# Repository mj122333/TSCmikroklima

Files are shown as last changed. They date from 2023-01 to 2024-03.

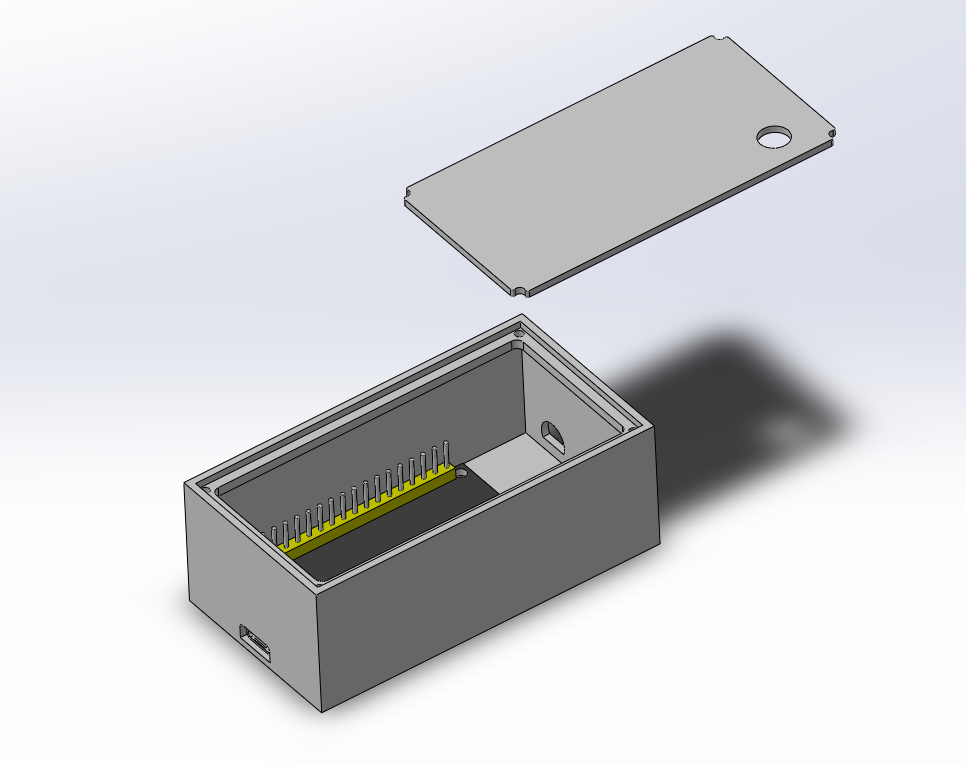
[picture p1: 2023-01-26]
node/3D_printing/slike/asembli_solid_noBatt_img2.PNG

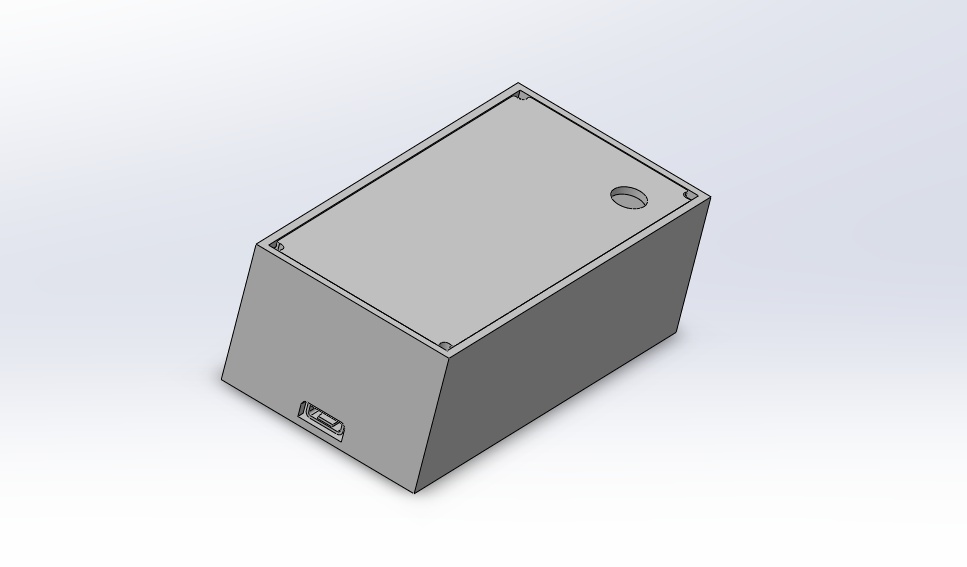
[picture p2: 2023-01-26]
node/3D_printing/slike/asembli_solid_noBatt_img1.PNG

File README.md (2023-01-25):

<div align="center">

[][contributors-url]
[][stars-url]

</div>

# TSC Mikroklima

TSC Mikroklima je projekt koji se bavi izgradnjom IoT sistema za mjerenje raznih parametara u školi.  
Sistem koristi senzore koji mjere: 
* temperaturu
* vlagu
* pritisak zraka
* otvorene prozore

Podaci se prikupljaju i prenose na cloud platformu gdje se obrađuju i prikazuju na različite načine, kao što su grafovi, tabele i mape. Cilj projekta
je pružiti školi uvid u stanje učionica i pomoći u održavanju optimalnih uvjeta za učenje. Također, sistem će biti dostupan putem web sučelja za lakše praćenje i 
upravljanje.Sada radimo na izgradnji i testiranju sistema i planiramo ga uključiti u školske aktivnosti u najkraćem mogućem roku.

Ovaj projekt sadrži sljedeće jezike/frameworke/biblioteke:
* [][Cpp-url]
* [][JSON-url]
* [][PHP-url]
* [][MySQL-url]
* [][JS-url]

<!-- GETTING STARTED -->
## Korištenje
pojašnjanje kako koristiti djelove ovog projekta.

### JSON upit za [submit.php](https://github.com/mj122333/TSCmikroklima/blob/main/server/submit.php)
Objašnjenje:

```JSON
{
  "MAC": "#MAC adresa uređaja koji šalje POST zahtjev",
  "temp": {
    "#adresa senzora za temperaturu": "#temperatura u decimalnom zapisu",
    "adresa sljedećeg senzora za temperaturu": "#temperatura u decimalnom zapisu",
    "adresa n-tog senzora za temperaturu": "#temperatura u decimalnom zapisu"
  },
  "statusObjekt": {
    "#pin senzora za status  objekta": "#je li prozor otvoren",
    "#pin sljedećeg senzora za status objekta": "#je li prozor otvoren",
    "#pin n-tog senzora za status objekta": "#je li prozor otvoren"
  }
}
```

Primjer:
```JSON
{
  "MAC": "01-23-45-67-89-AB",
  "temp": {
    "0x123456789ABCDEF0": 23.42,
    "0x123456789ABCDEF1": 22,
    "0x123456789ABCDEF2": 21.1
  },
  "statusObjekt": {
    "1": 1,
    "4": 0,
    "23": 1
  }
}
```
[Primjer upita u Postman-u](https://github.com/mj122333/TSCmikroklima/blob/main/server/skola-IoT.postman_collection.json) (importati u Postman)

[CPP]: https://img.shields.io/badge/C++-909DAB?style=for-the-badge&logo=cplusplus&logoColor=00599C
[CPP-url]: https://isocpp.org/

[JSON]: https://img.shields.io/badge/JSON-000?style=for-the-badge&logo=JSON
[JSON-url]: https://www.json.org/

[PHP]: https://img.shields.io/badge/PHP-777BB4?style=for-the-badge&logo=php&logoColor=333
[PHP-url]: https://isocpp.org/

[MySQL]: https://img.shields.io/badge/MySQL-4479A1?style=for-the-badge&logo=mysql&logoColor=FFF
[MySQL-url]: https://www.mysql.com/

[JS]: https://img.shields.io/badge/javascript-000000?style=for-the-badge&logo=javascript&logoColor=F7DF1E
[JS-url]: https://www.javascript.com/

[contributors-shield]: https://img.shields.io/github/contributors/mj122333/TSCmikroklima.svg?style=for-the-badge
[contributors-url]: https://github.com/mj122333/TSCmikroklima/graphs/contributors

[stars-shield]: https://img.shields.io/github/stars/mj122333/TSCmikroklima.svg?style=for-the-badge
[stars-url]: https://github.com/mj122333/TSCmikroklima/stargazers

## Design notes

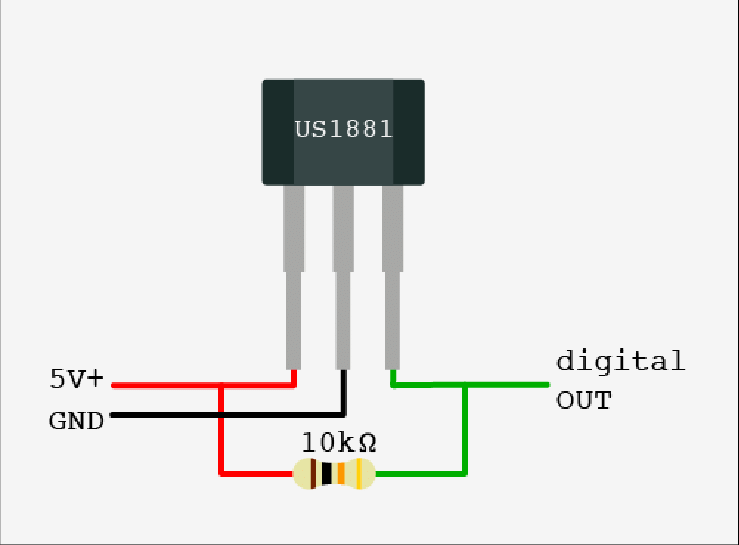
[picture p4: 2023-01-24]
node/scheme/komponente_pinout/us1881_hall.png

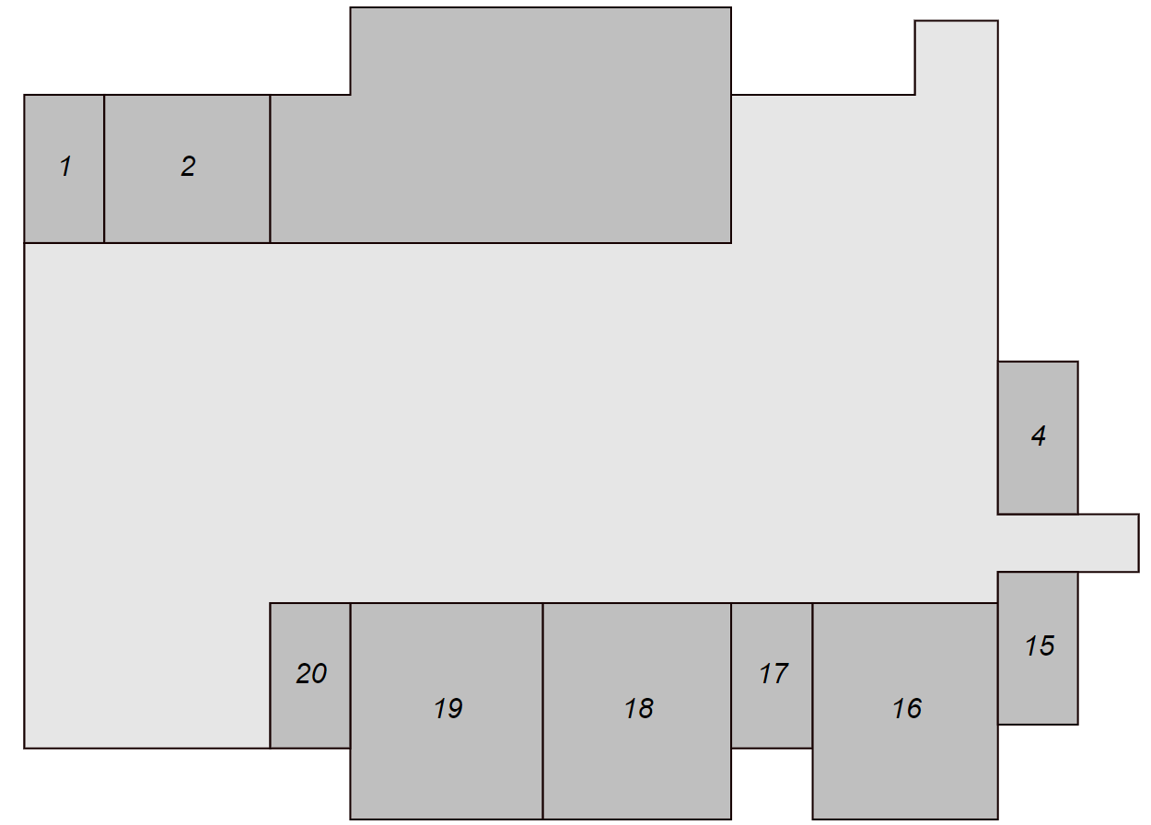
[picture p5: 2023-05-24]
server/slike/tlocrt-prizemlje-tv.png

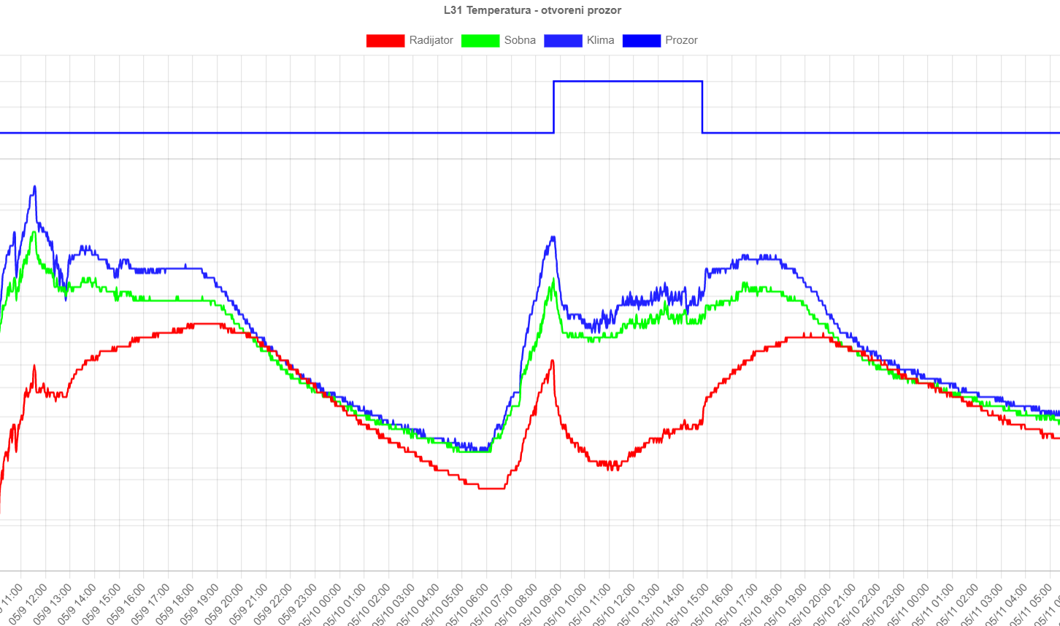
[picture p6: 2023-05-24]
server/slike/graf.png

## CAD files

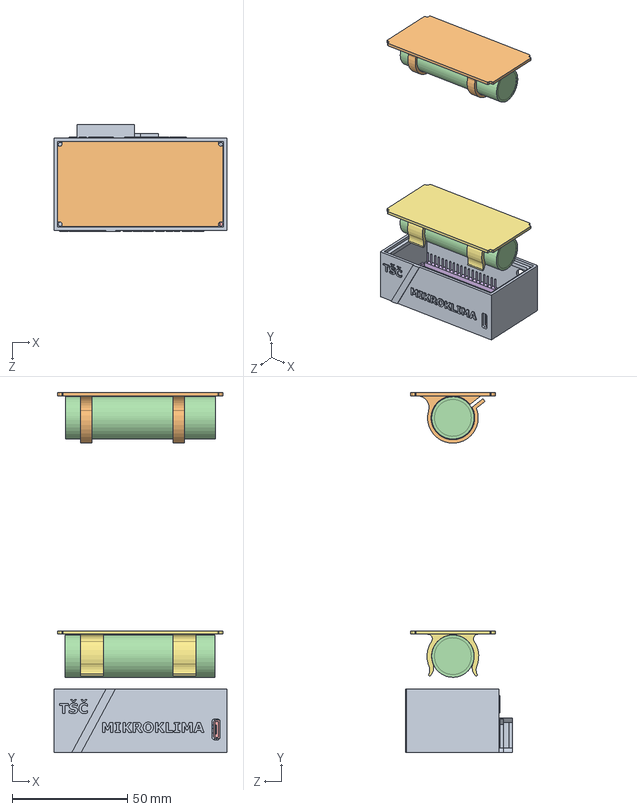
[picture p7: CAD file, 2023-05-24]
node/3D_printing/asembli_solid_Batt.SLDASM
75.0 x 156.1 x 46.5 mm
main_box_donjiDio_sBaterijom
main_box_poklopac_sBaterijom
main_ziceClamp_bezBaterije
battery_model x 2
charge_controller
ESP32_model
main_box_poklopac_sBaterijom_NoScrews

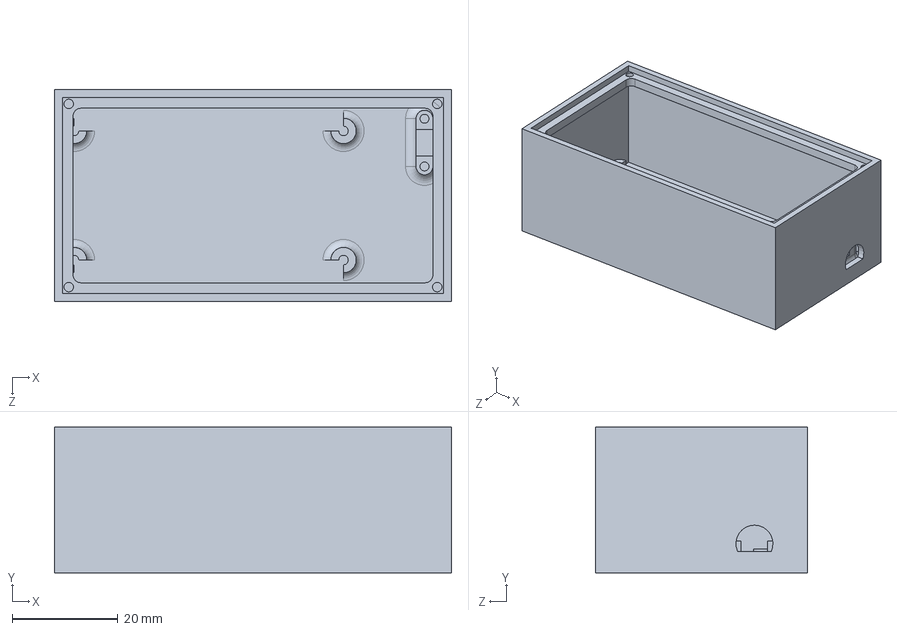
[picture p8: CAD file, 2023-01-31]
node/3D_printing/Main_box/bez_baterije/main_box_donjiDio_bezBaterije.SLDPRT
75.0 x 27.5 x 40.0 mm

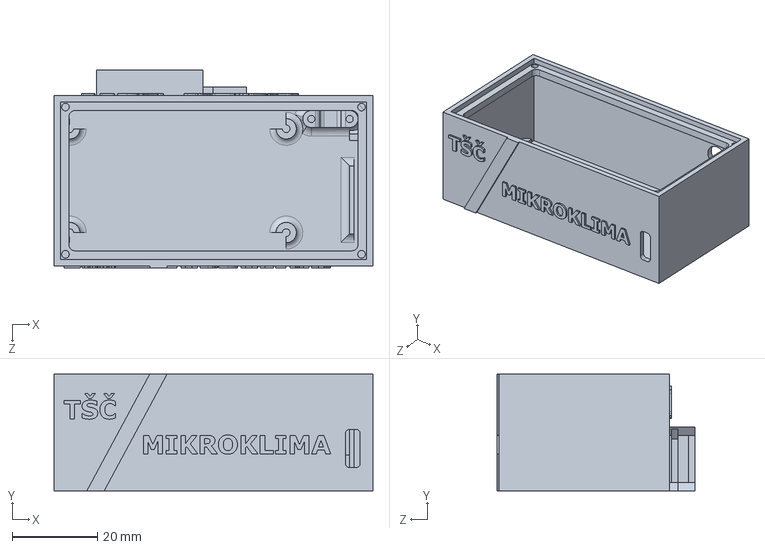
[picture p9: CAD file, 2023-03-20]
node/3D_printing/Main_box/main_box_donjiDio_sBaterijom.SLDPRT
75.0 x 27.5 x 46.5 mm

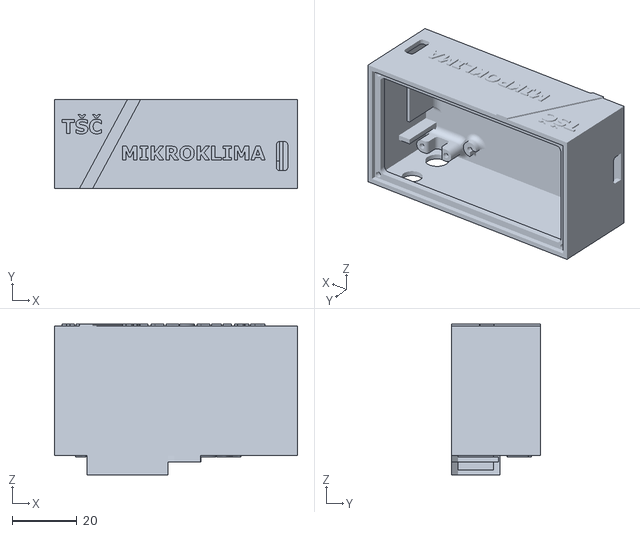
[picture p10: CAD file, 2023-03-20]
node/3D_printing/3D_printing_stl/main_box_donjiDio_sBaterijom.STL
75.0 x 27.5 x 46.5

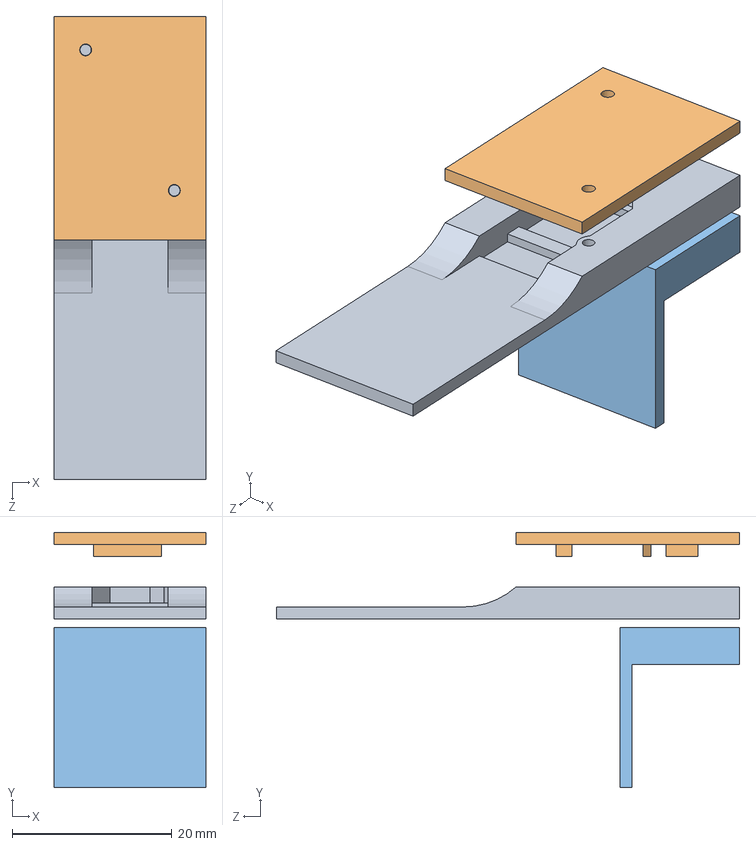
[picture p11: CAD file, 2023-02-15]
node/3D_printing/asembli_senzor_prozor.SLDASM
19.0 x 31.9 x 58.0 mm
hall_mount_zaProzor_kutijica
hall_mount_zaProzor_poklopac
magnet_mount

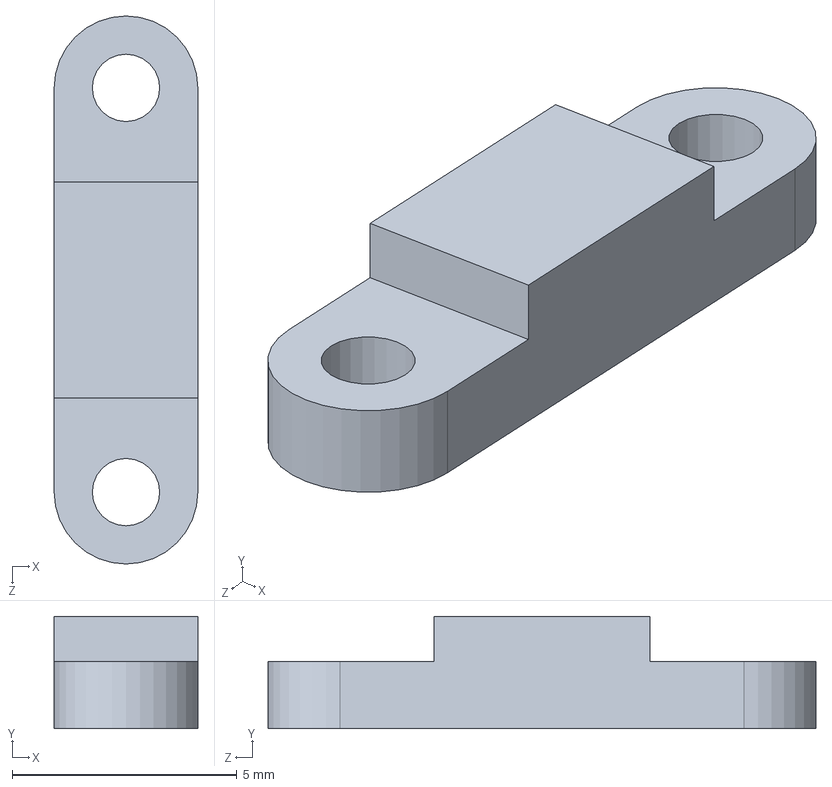
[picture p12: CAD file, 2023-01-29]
node/3D_printing/Main_box/bez_baterije/main_ziceClamp_bezBaterije.SLDPRT
3.20 x 2.50 x 12.2 mm

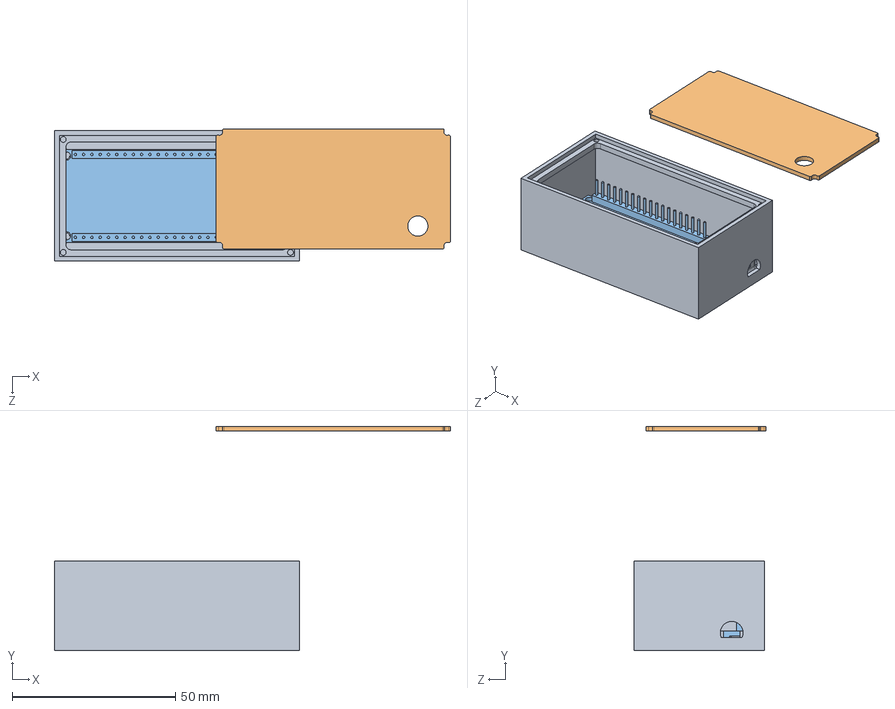
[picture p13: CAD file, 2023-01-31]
node/3D_printing/asembli_solid_noBatt.SLDASM
121.3 x 68.8 x 40.6 mm
main_box_donjiDio_bezBaterije
main_box_poklopac_bezBaterije
ESP32_model

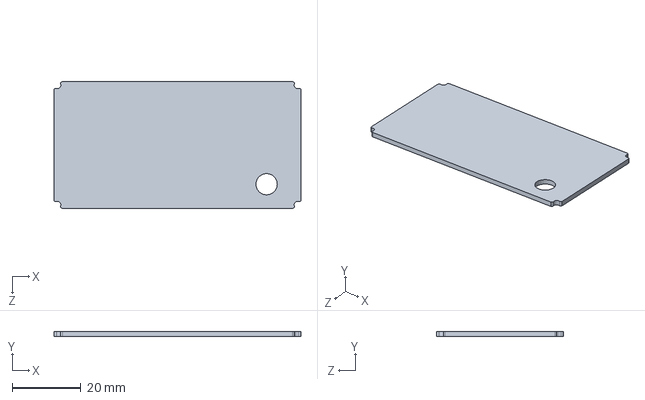
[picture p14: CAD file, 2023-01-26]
node/3D_printing/Main_box/bez_baterije/main_box_poklopac_bezBaterije.SLDPRT
71.8 x 1.50 x 36.8 mm

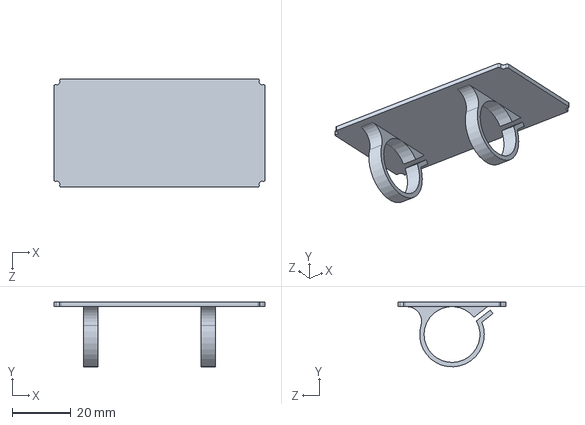
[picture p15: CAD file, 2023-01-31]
node/3D_printing/Main_box/main_box_poklopac_sBaterijom.SLDPRT
71.8 x 22.0 x 36.8 mm

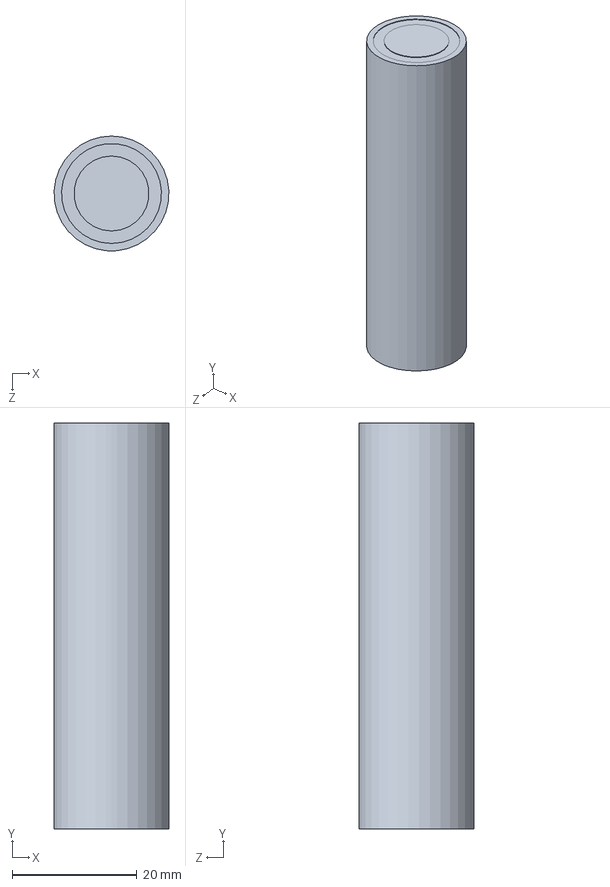
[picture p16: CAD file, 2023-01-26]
node/3D_printing/3D_component_models/battery_model.SLDPRT
18.4 x 65.0 x 18.4 mm

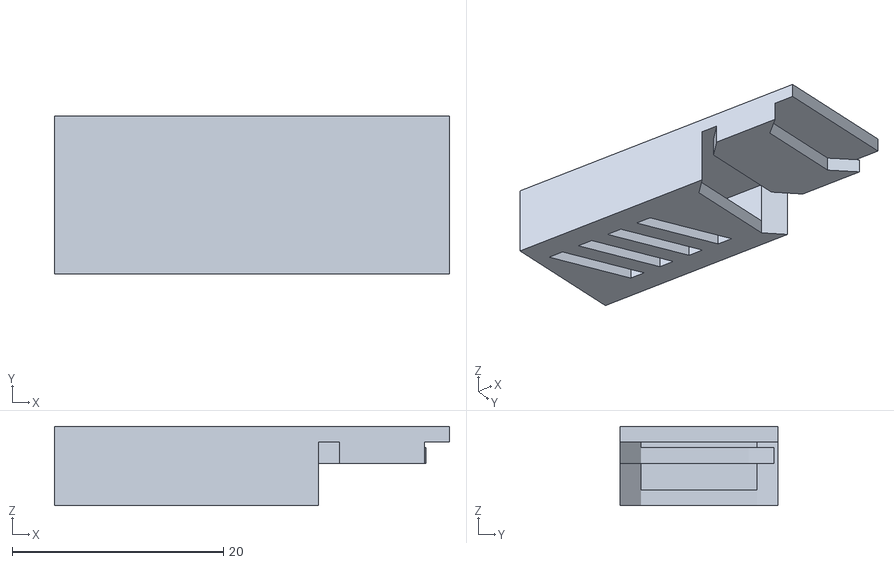
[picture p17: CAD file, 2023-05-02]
node/3D_printing/3D_printing_stl/room_temp.STL
37.4 x 15.0 x 7.50

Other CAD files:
node/3D_printing/step_files_blend/main_box_donjiDio_sBaterijom.STEP
node/3D_printing/3D_printing_stl/main_box_poklopac_sBaterijom.STL
node/3D_printing/3D_printing_stl/main_box_donjiDio_bezBaterije.STL
node/3D_printing/3D_printing_stl/main_ziceClamp_bezBaterije.STL
node/3D_printing/step_files_blend/main_ziceClamp_bezBaterije.STEP
node/3D_printing/3D_printing_stl/main_box_poklopac_bezBaterije.STL
node/3D_printing/senzori_kucista/room_temp.SLDPRT
node/3D_printing/3D_component_models/ESP32_model.SLDPRT
node/3D_printing/3D_component_models/charge_controller.SLDPRT
node/3D_printing/3D_printing_stl/18b20_mount_radijator.STL
node/3D_printing/3D_printing_stl/hall_mount_zaProzor_kutijica.STL
node/3D_printing/3D_printing_stl/hall_mount_zaProzor_poklopac.STL
node/3D_printing/3D_printing_stl/magnet_mount.STL
node/3D_printing/3D_printing_stl/main_box_poklopac_sBaterijom_NoScrews.STL
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

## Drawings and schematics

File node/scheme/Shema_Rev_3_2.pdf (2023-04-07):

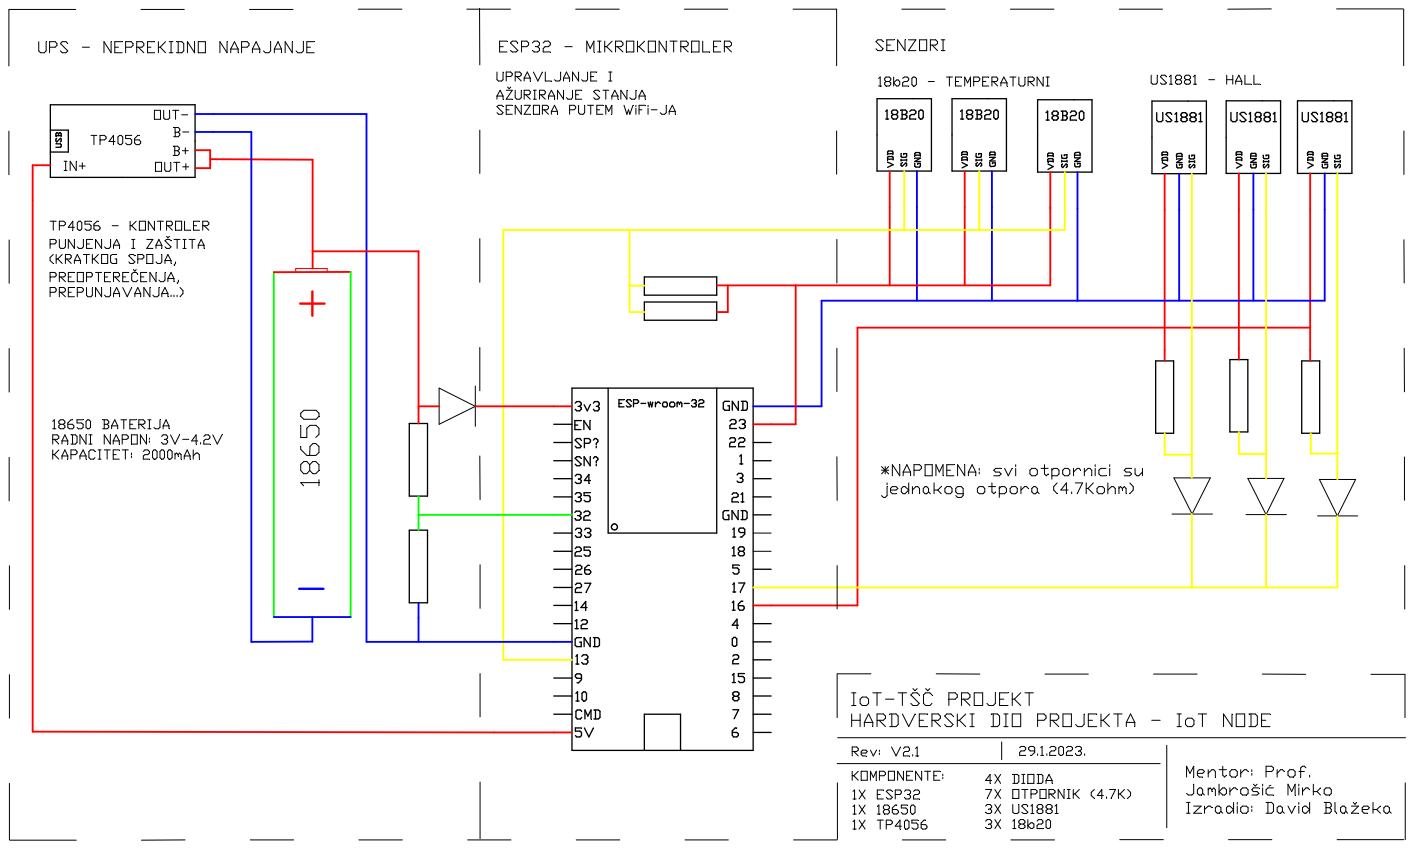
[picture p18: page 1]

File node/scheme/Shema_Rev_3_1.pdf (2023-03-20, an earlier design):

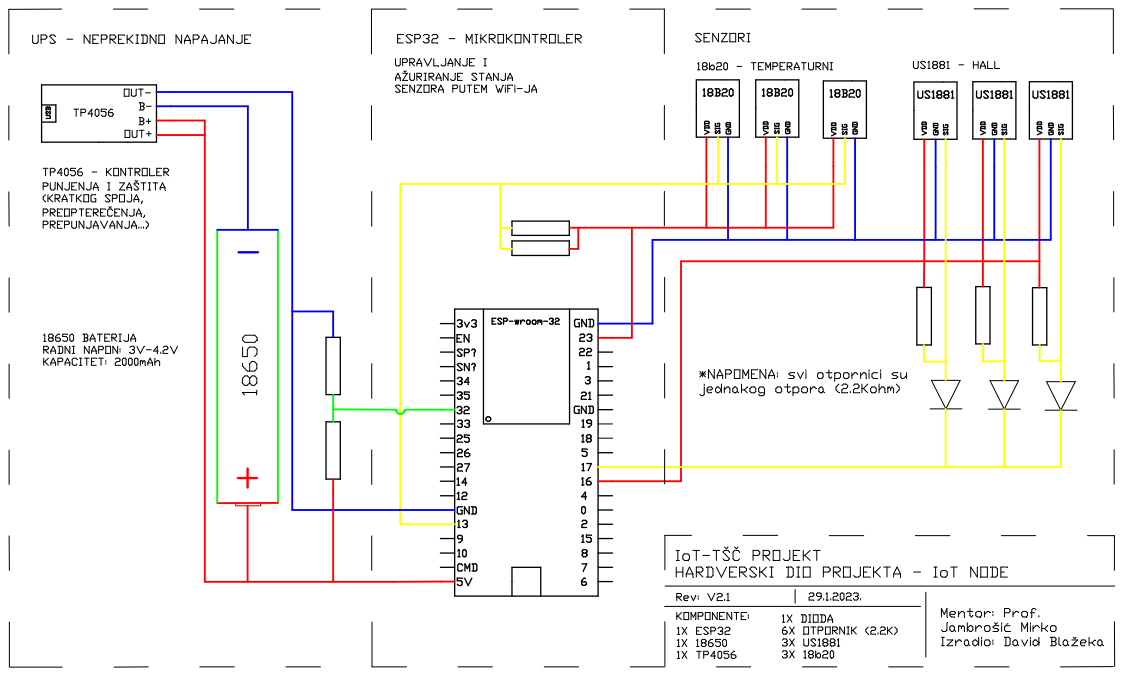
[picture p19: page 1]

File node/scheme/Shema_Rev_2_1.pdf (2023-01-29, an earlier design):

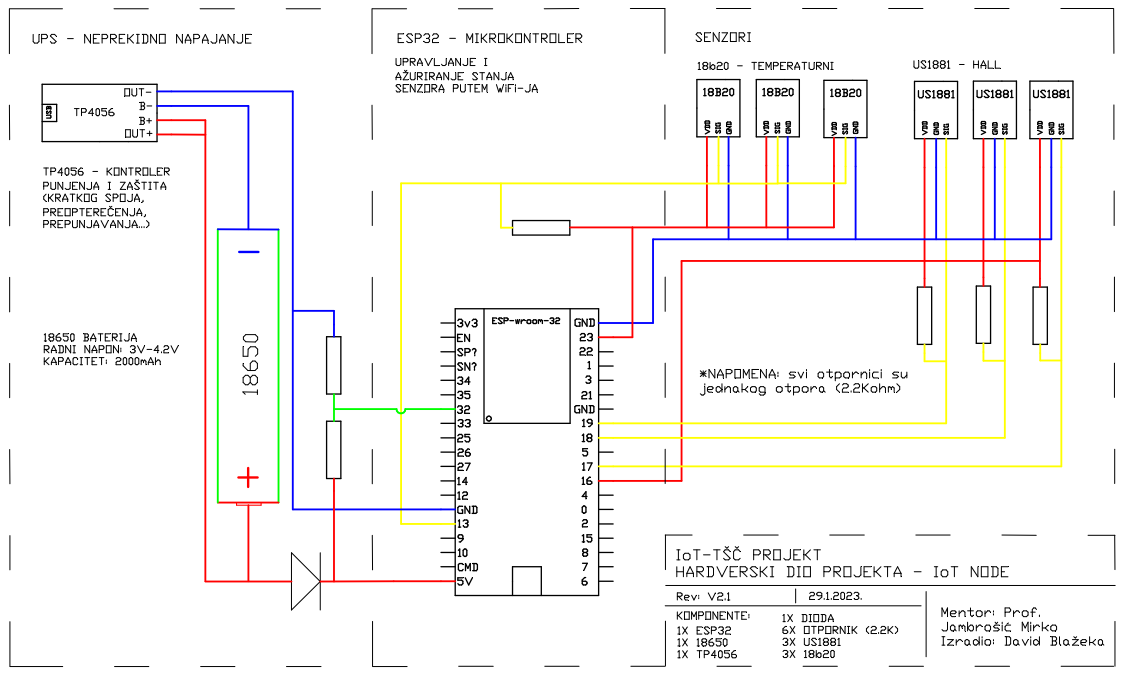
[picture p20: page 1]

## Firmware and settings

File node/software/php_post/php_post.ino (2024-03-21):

// kod za custom implementaciju...

#include <DallasTemperature.h>
#include <HTTPClient.h>
#include <OneWire.h>
#include <WiFiManager.h> // https://github.com/tzapu/WiFiManager

bool wm_nonblocking = false; // change to true to use non blocking
WiFiManager wm;
WiFiManagerParameter custom_field;

String serverName = "https://jambrosic.xyz/mikroklima/submit.php";

unsigned long lastTime = 0;
unsigned long timerDelay = 60000;
#define uS_TO_S_FACTOR 1000000
#define TIME_TO_SLEEP  60
String key = "esp32";  // super tajni key
String macAdresa = "";
String zaSlanjeT = "";
String zaSlanjeH = "";
String zaSlanjeM = "";
int broj_senzora = 0;
bool led_stanje = LOW;
bool zadnjeStanjeHall[3];
bool statusObjekt[3];
#define ONE_WIRE_BUS 13
#define B20_POWER 23
#define HALL_POWER 16
#define HALL_READ1 17
//#define HALL_READ2 18
//#define HALL_READ3 19
#define BATT 32
#define RED_LED 5
#define GREEN_LED 18
#define BLUE_LED 19

OneWire oneWire(ONE_WIRE_BUS);
DallasTemperature sensors(&oneWire);
DeviceAddress Thermometer;

void setup() {
    Serial.begin(115200);
    pinMode(21, OUTPUT);
    digitalWrite(21, HIGH); // status led
    pinMode(RED_LED, OUTPUT);
    pinMode(GREEN_LED, OUTPUT);
    pinMode(BLUE_LED, OUTPUT);
    delay(2000);
    Serial.println("Spajanje");
    Serial.print("MAC: ");
    macAdresa = WiFi.macAddress();
    Serial.println(macAdresa);
    spoji();
    spojeno();
    Serial.println("");
    Serial.print("IP: ");
    Serial.println(WiFi.localIP());
    Serial.println(WiFi.RSSI());
    pinMode(HALL_POWER, OUTPUT);
    pinMode(HALL_READ1, INPUT_PULLUP);
    //pinMode(HALL_READ2, INPUT_PULLUP);
    //pinMode(HALL_READ3, INPUT_PULLUP);
    pinMode(BATT, INPUT);
    pinMode(B20_POWER, OUTPUT);
    digitalWrite(B20_POWER, HIGH);  // no deep sleep
    esp_sleep_enable_timer_wakeup(TIME_TO_SLEEP * uS_TO_S_FACTOR);
}

void loop() {
    /*
     * slanje podataka, određeni interval vremena (timerDelay)
     * ako dođe do promjene u statusObjekt informacije se šalju odmah
     * interval slanja podataka neovisan je o promjeni statusaObjekta (šalje
     * podatke na timerDelay)
     */
    //if ((millis() - lastTime) > timerDelay) { 
        mjeri_temperaturu();  // funkcija koja ažurira temperature
        get_metadata();       // WiFi status i baterija
        hallRefresh();        // očitavanje stanja hall senzora
        pushData();  // funkcija koja šalje vrijednosti Gotalu i Biškupu
      //  lastTime = millis();
    //}
    WiFi.disconnect();
    off();
    Serial.flush(); 
    esp_deep_sleep_start();  
}

void hallRefresh() {                // void funkcija očitanja statusaObjekta
    digitalWrite(HALL_POWER, LOW);  // reset hall senzora
    delay(100);
    digitalWrite(HALL_POWER, HIGH);
    delay(100);  // pricekati da se hallovi stabiliziraju?
    zaSlanjeH = "";
    zaSlanjeH = ",\"statusObjekt\" : {";
    for (int i = 0; i < 3; i++) { //do 3 za 3 hall senzora
        statusObjekt[i] =
            digitalRead(17);  // 17, 18, 19 su ulazi senzora statusObjekt-a, obrisano + i jer se koristi samo jedan pin
        delay(20);
        if (statusObjekt[i] !=
            digitalRead(17))  // ako dva slijedna ocitanja daju razlicite
                                  // vrijednosti -> preskoci
            continue;
        /*
         //ovaj dio moramo prodiskutirati
         if(zadnjeStanjeHall[i] != statusObjekt[i]){//
           zadnjeStanjeHall[i] = statusObjekt[i]; //ako je stanje različito
         prijašnjem, zapisuje se u listu lastTime = millis() + timerDelay;
         //Slanje ažuriranih podataka, odmah (ukoliko je doslo do promjene barem
         jednog senzora)
         }
         //ovaj dio se koristio kod instantnog ažuriranja podataka (čim se
         promjenilo stanje prozora)
         */
        zaSlanjeH +=
            "\"" + String(17 + i) + "\" : \"" + statusObjekt[i] +
            "\"";  // spremanje stanja u zaSlanjeH string (u json formatu)
        if (i != 2) zaSlanjeH += ",";
    }
    zaSlanjeH += "}";
}

void pushData() {
    if (WiFi.status() == WL_CONNECTED) {
        spojeno();
        HTTPClient http;

        http.begin(serverName.c_str());
        Serial.println(serverName.c_str());
        http.addHeader("Content-Type", "application/json");

        // String jsonData =  "{\"MAC\" : \"" + macAdresa + "\",\"key\" :
        // \"esp32\",\"temp\" : {\"0xtest1\" : \"15\",\"0xtest2\" : \"20\" ,
        // \"0xtest3\" : \"25\"}}";

        String jsonData = "{\"MAC\" : \"" + macAdresa + "\",\"key\" : \"" +
                          key + "\"," + zaSlanjeT + zaSlanjeH + zaSlanjeM + "}";

        Serial.println(jsonData); // debug u konzoli
        zaSlanjeT = "";  // reset stringa za temperature
        zaSlanjeH = "";  // reset stringa za statusObjekta (hall)
        zaSlanjeM = "";  // reset stringa za metadata

        int httpResponseCode = http.POST(jsonData.c_str());

        if (httpResponseCode > 0) {
            Serial.print("HTTP Response code: ");
            Serial.println(httpResponseCode);
            String payload = http.getString();
            Serial.println(payload);
        } else {
            Serial.print("Error code: ");
            Serial.println(httpResponseCode);
        }
        http.end();
    } else {
        spoji();
    }
}

void get_metadata() {
    zaSlanjeM = ",\"metadata\" : {\"wifi_rssi\" : \"";
    zaSlanjeM += WiFi.RSSI();
    zaSlanjeM += "\",\"baterija\" : \"";
    float ulazA = analogRead(BATT);
    float napon = ulazA / 4096 * 6.6;  // 3.3V nominal, naponsko djelilo 1/2
    zaSlanjeM += uint16_t((napon + 0.3)*1000);          //+0.3 kalibracija, mV conv
    zaSlanjeM += "\"}";
}

void mjeri_temperaturu() {
    digitalWrite(B20_POWER, HIGH);
    delay(1000);
    sensors.begin();  // inicijalizacija senzora u svakom krugu očitanja (omogućuje hot-swap)
    delay(1000);
    broj_senzora = sensors.getDeviceCount();  // spremanje broja senzora
    sensors.requestTemperatures();  // očitavanje temperatura pomoću biblioteke
    delay(100);
    zaSlanjeT += "\"temp\" : {\"";  // početak json dijela s temperaturnim senzorima
    for (int sen = 0; sen < broj_senzora; sen++) {
        if (sensors.getTempCByIndex(sen) == -127) continue;
        sensors.getAddress(Thermometer, sen);
        zaSlanjeT += printAddress(Thermometer);  // očitavanje adrese
        zaSlanjeT += "\" : \"";
        zaSlanjeT += sensors.getTempCByIndex(sen);  // očitavanje temperature
        if (sen != broj_senzora - 1) zaSlanjeT += "\",\"";
        delay(500);  // reading cooldown, u fazi testiranja/traženja problema
    }
    zaSlanjeT += "\"}";
    digitalWrite(B20_POWER, LOW);
}

String printAddress(DeviceAddress deviceAddress)  // funkcija za adresu temperaturnih senzora
{
    String adresa = "0x";
    for (uint8_t i = 0; i < 8; i++) {
        adresa += String(deviceAddress[i], HEX);
    }
    return adresa;
}

void spajanje(){
  digitalWrite(GREEN_LED, LOW);
  digitalWrite(BLUE_LED, HIGH);
  digitalWrite(RED_LED, LOW);
}

void spojeno(){
  digitalWrite(RED_LED, HIGH);
  digitalWrite(GREEN_LED, LOW);
  digitalWrite(BLUE_LED, LOW);
}

void off(){
  digitalWrite(RED_LED, HIGH);
  digitalWrite(GREEN_LED, HIGH);
  digitalWrite(BLUE_LED, HIGH);
}

void spoji(){
  spajanje();
  WiFi.mode(WIFI_STA); // explicitly set mode, esp defaults to STA+AP  
  Serial.begin(115200);
  Serial.setDebugOutput(true);  
  delay(3000);
  Serial.println("\n Starting");
  
  // wm.resetSettings(); // wipe settings

  if(wm_nonblocking) wm.setConfigPortalBlocking(false);

  // add a custom input field
  int customFieldLength = 40;
  const char* custom_radio_str = "<br/><label for='customfieldid'>Custom Field Label</label><input type='radio' name='customfieldid' value='1' checked> One<br><input type='radio' name='customfieldid' value='2'> Two<br><input type='radio' name='customfieldid' value='3'> Three";
  new (&custom_field) WiFiManagerParameter(custom_radio_str); // custom html input
  
  wm.addParameter(&custom_field);
  wm.setSaveParamsCallback(saveParamCallback);

  std::vector<const char *> menu = {"wifi","info","param","sep","restart","exit"};
  wm.setMenu(menu);
  wm.setClass("invert");

  //wm.setSTAStaticIPConfig(IPAddress(10,0,1,99), IPAddress(10,0,1,1), IPAddress(255,255,255,0)); // set static ip,gw,sn
  // wm.setConnectTimeout(20); // how long to try to connect for before continuing
  wm.setConfigPortalTimeout(60); // auto close configportal after n seconds

  bool res;
  res = wm.autoConnect("TSC_mikroklima","password"); // password protected ap

  if(!res) {
    Serial.println("Failed to connect or hit timeout");
    ESP.restart();
  } 
  else {
    //if you get here you have connected to the WiFi    
    spojeno();
    Serial.println("connected...yeey :)");
  }
}

String getParam(String name){
  //read parameter from server, for customhmtl input
  String value;
  if(wm.server->hasArg(name)) {
    value = wm.server->arg(name);
  }
  return value;
}

void saveParamCallback(){
  Serial.println("[CALLBACK] saveParamCallback fired");
  Serial.println("PARAM customfieldid = " + getParam("customfieldid"));
}

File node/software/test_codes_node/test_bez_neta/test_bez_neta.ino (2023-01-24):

//kod za test jsona, OFFLINE!!
#include <OneWire.h>
#include <DallasTemperature.h>

unsigned long lastTime = 0;
unsigned long timerDelay = 10000;
String macAdresa = "";
String zaSlanjeT = "";
String zaSlanjeH = "";
int broj_senzora = 0;
bool zadnjeStanjeHall[3];
bool statusObjekt[3];
#define ONE_WIRE_BUS 13
#define HALL_POWER 16
#define HALL_READ1 17
#define HALL_READ2 18
#define HALL_READ3 19

OneWire oneWire(ONE_WIRE_BUS);
DallasTemperature sensors(&oneWire);
DeviceAddress Thermometer;
   
void setup() {
   Serial.begin(115200);
   macAdresa = "aa-B0-D0-63-C2-55";
   Serial.println(macAdresa);
   pinMode(HALL_POWER, OUTPUT);
   pinMode(HALL_READ1, INPUT);
   pinMode(HALL_READ2, INPUT);
   pinMode(HALL_READ3, INPUT);
}

void loop() {
  /*
   * slanje podataka, određeni interval vremena (timerDelay)
   * ako dođe do promjene u statusObjekt informacije se šalju odmah
   * interval slanja podataka neovisan je o promjeni statusaObjekta (šalje podatke na timerDelay)
   */
  if ((millis() - lastTime) > timerDelay) {
    mjeri_temperaturu(); //funkcija koja ažurira temperature
    pushData(); //funkcija koja šalje vrijednosti Gotalu i Biškupu
    lastTime = millis();
  }

  hallRefresh(); //"interrupt" funkcija statusObjekt-a (šalje podatke kod promjene, ne čeka timerDelay)
}

void hallRefresh(){ //void funkcija očitanja statusaObjekta
  digitalWrite(HALL_POWER, LOW); //reset hall senzora
  delay(10);
  digitalWrite(HALL_POWER, HIGH);

  zaSlanjeH = "";
  zaSlanjeH = ",\"statusObjekt\" : {";
  for(int i = 0; i < 3; i++){
    statusObjekt[i] = digitalRead(17+i); //17, 18, 19 su ulazi senzora statusObjekt-a
    if(zadnjeStanjeHall[i] != statusObjekt[i]){
      zadnjeStanjeHall[i] = statusObjekt[i]; //ako je stanje različito prijašnjem, zapisuje se u listu
      lastTime = millis() + timerDelay; //Slanje ažuriranih podataka, odmah
    }
    zaSlanjeH += "\"" + String(17+i) + "\" : \"" + statusObjekt[i] + "\""; //spremanje stanja u zaSlanjeH string (u json formatu)
    if(i != 2) zaSlanjeH += ",";
  }
  zaSlanjeH += "}";
}

void pushData(){
       //String jsonData =  "{\"MAC\" : \"" + macAdresa + "\",\"temp\" : {\"" + a1 + "\" : \"" + t1 + "\",\"" + a2 + "\" : \"" + t2 + "\" , \"" + a3 + "\" : \"" + t3 + "\"}, \"prozor\" : \"" + sp + "\"}";
       String jsonData =  "{\"MAC\" : \"" + macAdresa + "\"," + zaSlanjeT + zaSlanjeH + "}";
       Serial.println(jsonData);
       zaSlanjeT = ""; //reset stringa za temperature
       zaSlanjeH = ""; //reset stringa za statusObjekta (hall)
}

void mjeri_temperaturu(){
  sensors.begin(); //inicijalizacija senzora u svakom krugu očitanja (omogućuje hot-swap)
  broj_senzora = sensors.getDeviceCount(); //spremanje broja senzora
  sensors.requestTemperatures(); //očitavanje temperatura pomoću biblioteke
  
  zaSlanjeT += "\"temp\" : {\""; //početak json dijela s temperaturnim senzorima
  for(int sen = 0; sen < broj_senzora; sen++){
    sensors.getAddress(Thermometer, sen);
    zaSlanjeT += printAddress(Thermometer); //očitavanje adrese
    zaSlanjeT += "\" : \"";
    zaSlanjeT += sensors.getTempCByIndex(sen); //očitavanje temperature
    if(sen != broj_senzora-1) zaSlanjeT += "\",\"";
  }
  zaSlanjeT += "\"}";
}

String printAddress(DeviceAddress deviceAddress) //funkcija za adresu temperaturnih senzora
{ 
    String adresa = "";
  for (uint8_t i = 0; i < 8; i++)
  {
    adresa += "0x";
    if (deviceAddress[i] < 0x10) adresa += "0";
    adresa += String(deviceAddress[i], HEX);
    if (i < 7) adresa += ", ";
  }
  return adresa;
}

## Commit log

2023-01-11 Primanje i slanje requesta
    + php kod koji prima json tekst i koristi ga
    + slanje post metode sa esp32
2023-01-15 dohvat id senzora
    dohvat ID senzora na temelju adrese (i2c) senzora
2023-01-17 final kod v1
    - slanje MAC adrese
    - slanje adrese senzora za temperaturu 3x
    - slanje stanja prozora (bool)
    - slanje na određeni interval i odmah kad se prozor otvori (hall POWER off/on, reset)
    - auto restart ESP32 ako nije spojen na WiFi kod POST dijela
    [php_post.ino]
2023-01-17 Update php_post.ino
    Promjena temperatura iz stringa u float
2023-01-19 - esp32, dht11 za tv
2023-01-19 esp32 kod za dht11 (TV)
2023-01-24 Spremanje temperature
    Popravljeno spremanje temperature
    Popravljen zatipak u bazi podataka sa "VRIEJDNOST" u "VRIJEDNOST"
    Dodano malo pojašnjenje submit.php datoteke
2023-01-24 novi ažurirani kod
    - hot-swapable senzori
    - optimiziran način slanja (zaSlanjeT, zaSlanjeH)
    - dodani komentari
    [php_post.ino]
2023-01-24 popravljen reset halla (nova verzija)
    [php_post.ino]
2023-01-25 update kod - ignor bad sensor
2023-01-26 3d_modeli_komponente
    -esp32
    -baterija
    -punjač
    [ESP32_model.SLDPRT, battery_model.SLDPRT, charge_controller.SLDPRT]
2023-01-26 dodani dxf (pinout)
    [esp32_schem.dxf]
2023-01-26 Big 3D update
    -novi modeli
    -nova kutija (bez baterije)
    -novi poklopac
    -nove slike (assembly)
    -generirani stl za 3D printanje
    [asembli_solid_noBatt.SLDASM, main_box_donjiDio_bezBaterije.SLDPRT, main_box_donjiDio_bezBaterije.STL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]
2023-01-28 shema update
    [esp32_schem.dwg]
2023-01-29 shceme rev2_1
    [esp32_schem.dwg]
2023-01-29 shema 18b20 power pin changed
    [esp32_schem.dwg]
2023-01-29 3d printed box - ziceClamp
    [main_box_donjiDio_bezBaterije.SLDPRT, main_box_donjiDio_bezBaterije.STL, main_ziceClamp_bezBaterije.SLDPRT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]
2023-01-30 Dodan prikaz podataka direktno na tlocrtu
    ispis sobne temperature te temperature na klimi i radijatoru
2023-01-31 node i 3d printing update
    [18b20_mount_radijator.SLDPRT, 18b20_mount_radijator.STL, asembli_solid_noBatt.SLDASM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]
2023-01-31 Dodani indikatori za otvoreni i zatvoreni prozor te upozorenja
    Crveno upozorenje se ispisuje kada je temperatura nekog senzora > 35°C i otvoren prozor, a žuto ako se to dogodilo u poslijednih 8h
2023-01-31 3d printing stuff
    [asembli_solid_Batt.SLDASM, main_box_donjiDio_sBaterijom.SLDPRT, main_box_donjiDio_sBaterijom.STL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]
2023-02-02 podebljani dio za drzac baterije
    [asembli_solid_Batt.SLDASM, main_box_poklopac_sBaterijom_NoScrews.SLDPRT, main_box_poklopac_sBaterijom_NoScrews.STL]
2023-02-05 cekanje da se hallovi "stabiliziraju"
    - dodano 100ms nakon ukljucivanje hall senzora da se eventualno stabiliziraju
    - provjera debounce-a ?
2023-02-06 vracanje - provjera halla
    vracanje na slanje samo u slucaju da je doslo do promjene stanja senzora hall-a
2023-02-07 UPDATE //fixno svaku min
    [php_post.ino]
2023-02-11 3d print update
    [hall_mount_zaProzor_kutijica.SLDPRT, hall_mount_zaProzor_kutijica.STL, hall_mount_zaProzor_poklopac.SLDPRT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]
2023-02-11 3d pritn update
    [hall_mount_zaProzor_kutijica.SLDPRT, main_box_poklopac_sBaterijom_NoScrews.SLDPRT, main_box_poklopac_sBaterijom_NoScrews.STL]
2023-02-12 3d print fix
    [asembli_senzor_prozor.SLDASM, hall_mount_zaProzor_kutijica.SLDPRT, hall_mount_zaProzor_kutijica.STL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]
2023-02-13 3d update
    [hall_mount_zaProzor_kutijica.SLDPRT, hall_mount_zaProzor_kutijica.STL]
2023-02-15 3D design //.step
    [18b20_mount_radijator.STEP, ESP32_model.STEP, asembli_senzor_prozor.SLDASM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]
2023-03-20 3d i shema
    [18b20_mount_radijator.SLDPRT, asembli_solid_Batt.SLDASM, esp32_schem.dwg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]
2023-03-27 responzivan graf i submit fix
    - responzivan graf za manje uređaje
    - provjera i brisanje pogrešnih informacija o temperaturi (spikeovi)
    - dodan file koji služi za izravnavanje grafa tako što briše definirane odskoke (trenutno onemogućen)
2023-03-30 dokumentacija i ostalo
    [esp32_schem.dwg]
2023-05-02 added deep sleep esp32
2023-05-09 3d main
    [tablet_holder.SLDPRT, tablet_holder.STL]
